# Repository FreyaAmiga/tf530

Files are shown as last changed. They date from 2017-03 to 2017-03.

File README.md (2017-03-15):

# TF530

** WARNING THIS IS BETA AT THE MOMENT

This repository contains all the files needed to produce a copy of my accelerator board.

The CPLD Required is a XC9572XL-10VQ64

Everything in this repository is released under the GNU GPLv2. You may create or base commercial PCBs from the work in this repository but you must make the sources for all derivative work available. 

## Firmware / Requirements

  * Xilinx ISE, 14.7 (the final version - other versions may work but this is the one I support)
  * JTAG Adaptor

[For more information visit my channel](https://www.youtube.com/c/TerribleFire)

##License

This project and all the files contained are released under the GNU GPLv2. If you build a modified version of the board you must supply the end user with all the sources (this can be a web link).

##The TerribleFire 530 board (Revision 2)

This board is now in Beta. It may not work in all circumstances but it has been verified to boot AmigaOS 1.3, 2.05 and 3.1 and run various games and desktop apps at 25Mhz. Operation is not guarunteed to be crash free but will work in most "happy path" situations.

I have only verified the HD interface with Compact Flash cards.
I have verified this board boots on Amiga 500 Rev 5, 6a, 8.1a

To buy 10 blank copies of the revision 2 board follow the following link.

http://dirtypcbs.com/store/designer/details/12476/1330/tf530-rev2b-zip

(Terrible Fire gets a $2 "cut" for each order... in reality this is a downpayment on future prototype board orders).

I accept no responsibiltiy for any damage to any equipment that results from the use of this board. IT IS ENTIRELY AT YOUR OWN RISK!

## Installation

Installation is exactly the same as the Kipper2k A508. Refer to http://www.kipper2k.com/a500fastmem.html

You need to connect the OVR and INT2 signals to the A500 header port. 

## What does the board look like

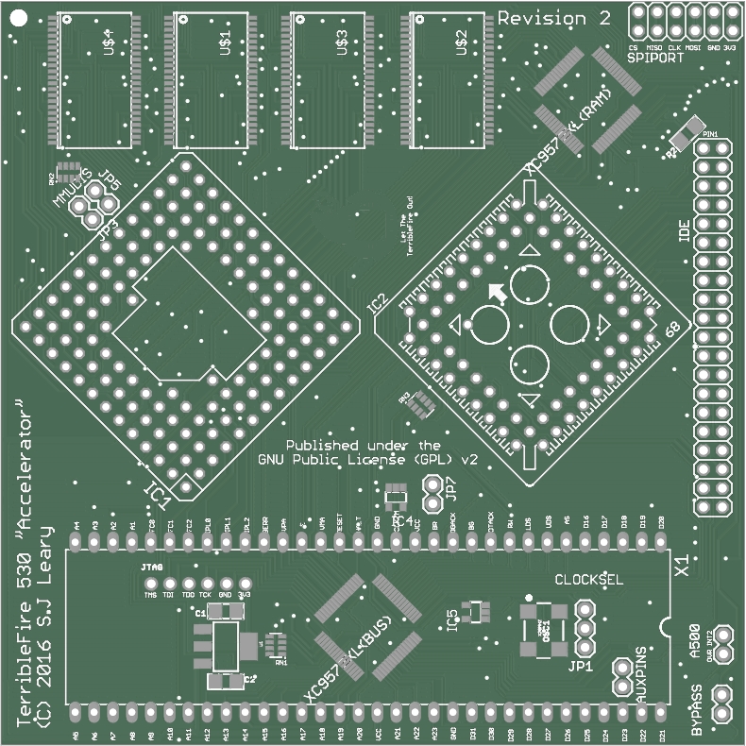
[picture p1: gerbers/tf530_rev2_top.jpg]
Image of Top of PCB


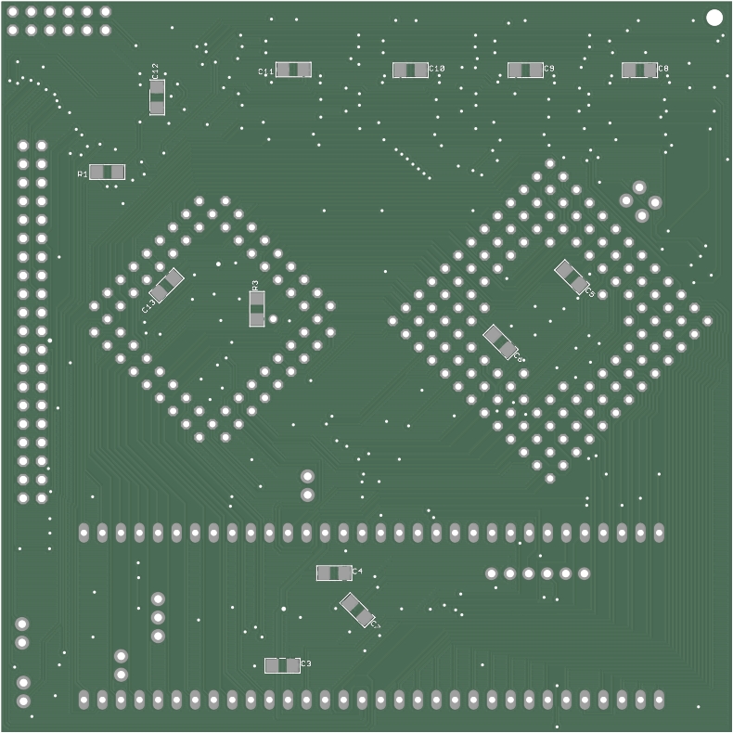
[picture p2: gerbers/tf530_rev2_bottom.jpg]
Image of Bottom of PCB


## The BOM 

| Qty | Value | Device | Package | Parts | Description | 
|-----|---|---|---|---|---|
| 1 | | MC68030RC | MPGA128 | IC1 | 68xxx PROCESSOR | 
| 1 | | MC68881FN-SOC | PLCC68-S | IC2 | 68xxx PROCESSOR |
| 1 | 10K | RESISTOR1206 | 1206 | R3 | Resistors |
| 13  | 10uF | CAP_CERAMIC1206 | 1206 | C1, C2, C3, C4, C5, C6, C7, C8, C9, C10, C11, C12, C13 | Ceramic Capacitors | 
| 2 | 47K | RESISTOR1206 | 1206 | R1, R2 | Resistors | 
| 2 | 74LVC1G17DBV | 74LVC1G17DBV | SOT23-5 | IC4, IC5 | Single Schmitt-Trigger Buffer | 
| 1 | A500 | JUMPER-2PTH | 1X02 | A500 | Jumper | 
| 4 | AS7C4096A-12TIN | AS7C4096A-12TCN | TSOP44-II | U$1, U$2, U$3, U$4 | |  
| 1 | AUXPINS | JUMPER-2PTH | 1X02 | AUXPINS | Jumper | 
| 1 | BYPASS | JUMPER-2PTH | 1X02 | BYPASS | Jumper (optional) | 
| 3 | CAY16-103J4LF | CAY16-103J4LF | RESCAXE80P320X160-8N | RN1, RN2, RN3 | Res Thick Film Array 10K Ohm  | 
| 1 | CDIS | JUMPER-2PTH | 1X02 | JP5 | Jumper |
| 1 | CLOCKSEL | JUMPER-3PTH | 1X03 | JP1 | | 
| 1 | EXT5V | JUMPER-2PTH | 1X02 | JP7 | Jumper |
| 1 | IDE CONNECTOR | PINHD-2X20 | 2X20 | IDE | PIN HEADER |
| 1 | JTAG | HEADER-1X6ROUND | 1X06_ROUND | JTAG | PIN HEADER |
| 1 | LM1117 | V_REG_LM1117SOT223 | SOT223 | U1 | 3.3V Voltage  Regulator LM1117 |
| 1 | MC68000 | MC68000P | DIL64 | X1 | 68xxx PROCESSOR SOCKET | 
| 1 | MMUDIS | JUMPER-2PTH | 1X02 | JP3 | Jumper | 
| 1 | SPI PORT | PINHD-2X6 | 2X06 | SPIPORT | PIN HEADER | 
| 1 | X24MHZ | OSCILLATOR | OSC_7X5MM | OSC1 | 24 Mhz llators |
| 2 | XC9572XL-10VQ64 | XC9572XL-VQ64 | VQ64 | XC9572XL(BUS), XC9572XL(RAM) | |

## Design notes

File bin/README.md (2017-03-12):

TF530 Binary Files
==================

These are binary files that i create to make life easy for people bringing up the TF530.

File Description

The .xsvf is a single file containing both JED files that should be playable by an xsvf player. If you dont have one you will need the jed files.

<date>_tf530_bus.jed - File for the first CPLD in the chain.
<date>_tf530_ram.jed - File for the second CPLD in the chain.

~~~~
  Chain Diagram
  
            -------         -------        
  TDI ---- |       |-->----|       | - - -|
           |  BUS  |       |  RAM  |      |
           |       |       |       |      |
            -------         -------       |
                                          |
  TDO -----<-------------------------<-----
~~~~

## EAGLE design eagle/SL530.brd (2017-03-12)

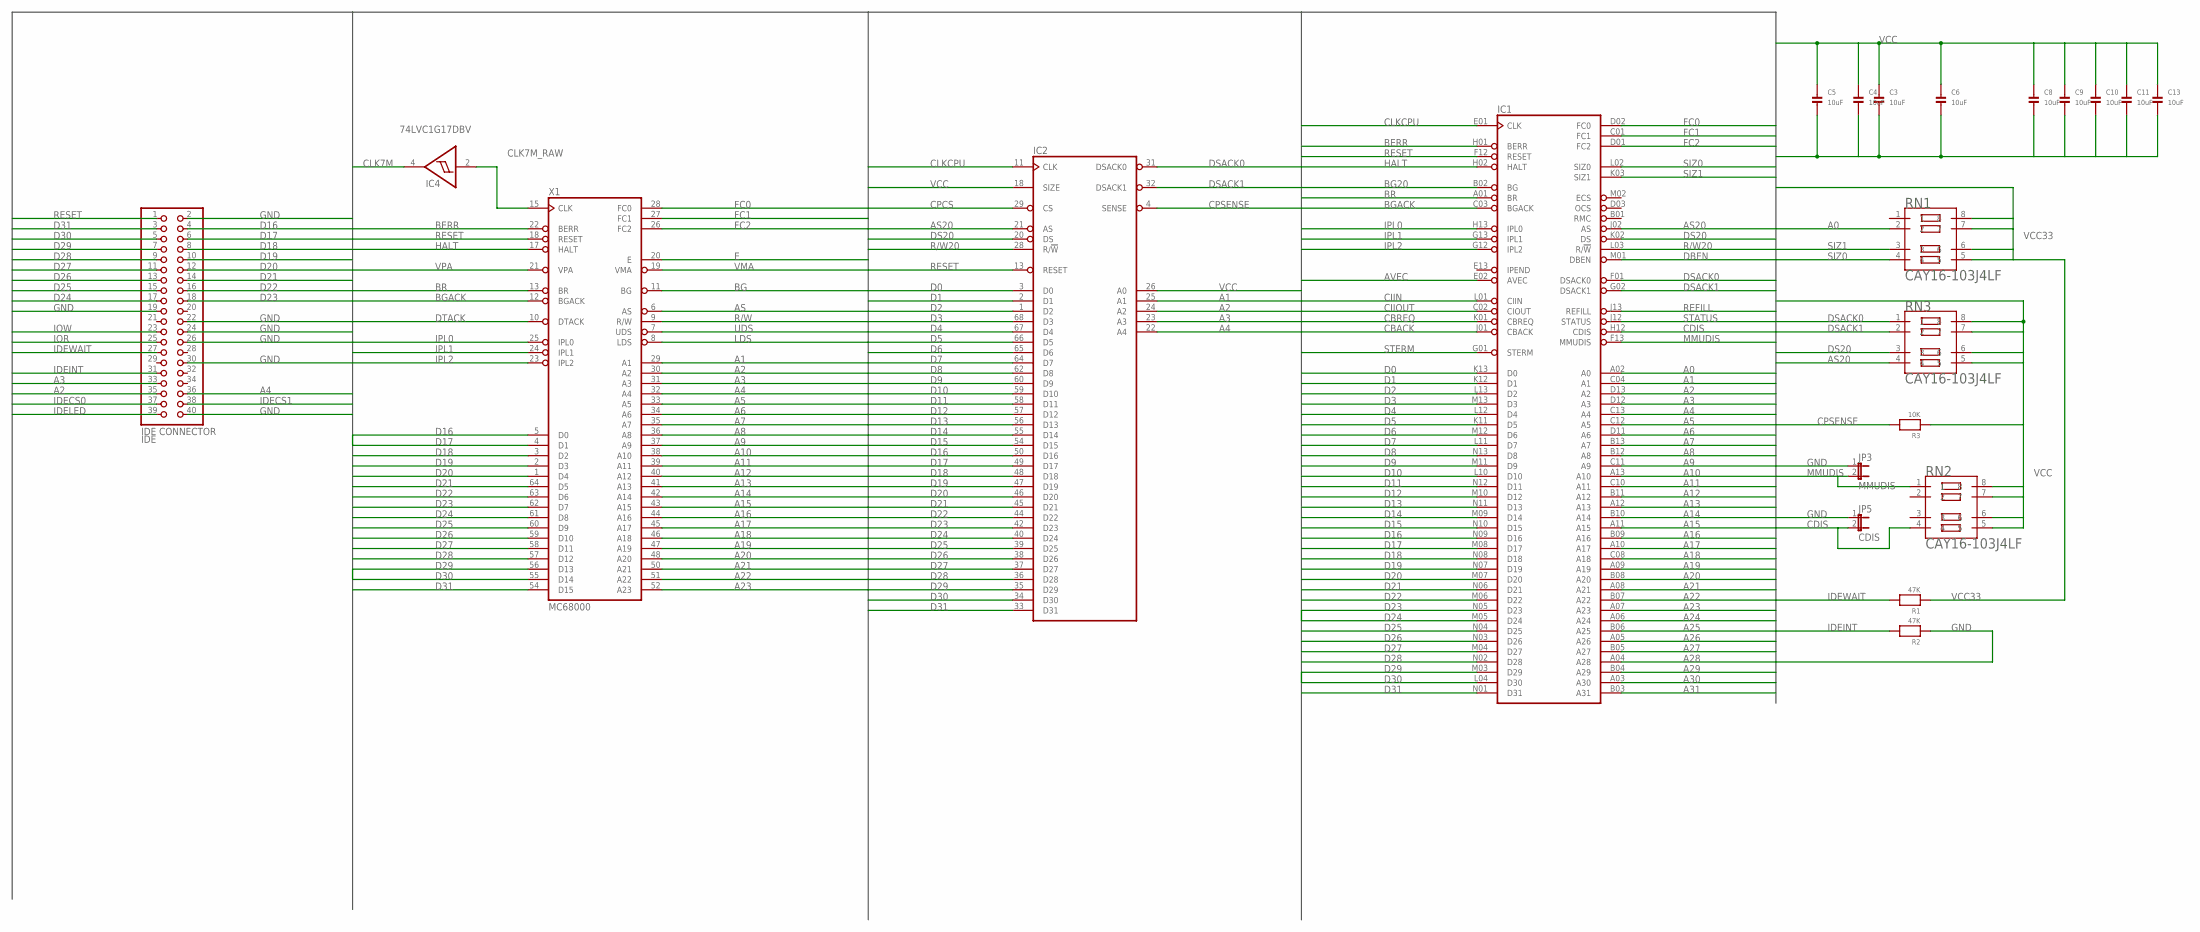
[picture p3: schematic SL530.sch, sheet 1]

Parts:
C3, C4, C5, C6, C8, C9, C10, C11, C13: 10uF; 1206
IC1: MC68030RC; MPGA128
IC2: MC68881FN-SOC; PLCC68-S
IC4: 74LVC1G17DBV; SOT23-5
IDE: IDE CONNECTOR; 2X20
JP3: MMUDIS; 1X02
JP5: CDIS; 1X02
R1, R2: 47K; 1206
R3: 10K; 1206
RN1, RN2, RN3: CAY16-103J4LF; RESCAXE80P320X160-8N
X1: MC68000; DIL64

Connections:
A0: IC1.A02 (A0), RN1.2; also elsewhere on the board
A1: IC1.C04 (A1), IC2.25 (A1), X1.29 (A1); also elsewhere on the board
A2: IC1.D13 (A2), IC2.24 (A2), IDE.35, X1.30 (A2); also elsewhere on the board
A3: IC1.D12 (A3), IC2.23 (A3), IDE.33, X1.31 (A3); also elsewhere on the board
A4: IC1.C13 (A4), IC2.22 (A4), IDE.36, X1.32 (A4); also elsewhere on the board
A5: IC1.C12 (A5), X1.33 (A5); also elsewhere on the board
A6: IC1.D11 (A6), X1.34 (A6); also elsewhere on the board
A7: IC1.B13 (A7), X1.35 (A7); also elsewhere on the board
A8: IC1.B12 (A8), X1.36 (A8); also elsewhere on the board
A9: IC1.C11 (A9), X1.37 (A9); also elsewhere on the board
A10: IC1.A13 (A10), X1.38 (A10); also elsewhere on the board
A11: IC1.C10 (A11), X1.39 (A11); also elsewhere on the board
A12: IC1.B11 (A12), X1.40 (A12); also elsewhere on the board
A13: IC1.A12 (A13), X1.41 (A13); also elsewhere on the board
A14: IC1.B10 (A14), X1.42 (A14); also elsewhere on the board
A15: IC1.A11 (A15), X1.43 (A15); also elsewhere on the board
A16: IC1.B09 (A16), X1.44 (A16); also elsewhere on the board
A17: IC1.A10 (A17), X1.45 (A17); also elsewhere on the board
A18: IC1.C08 (A18), X1.46 (A18); also elsewhere on the board
A19: IC1.A09 (A19), X1.47 (A19); also elsewhere on the board
A20: IC1.B08 (A20), X1.48 (A20); also elsewhere on the board
A21: IC1.A08 (A21), X1.50 (A21); also elsewhere on the board
A22: IC1.B07 (A22), X1.51 (A22); also elsewhere on the board
A23: IC1.A07 (A23), X1.52 (A23); also elsewhere on the board
A24: IC1.A06 (A24)
A25: IC1.B06 (A25)
A26: IC1.A05 (A26)
A27: IC1.B05 (A27)
A28: IC1.A04 (A28)
A29: IC1.B04 (A29)
A30: IC1.A03 (A30)
A31: IC1.B03 (A31)
AS: X1.6 (AS); also elsewhere on the board
AS20: IC1.J02 (AS), IC2.21 (AS), RN3.4; also elsewhere on the board
AVEC: IC1.E02 (AVEC); also elsewhere on the board
BERR: IC1.H01 (BERR), X1.22 (BERR); also elsewhere on the board
BG: X1.11 (BG); also elsewhere on the board
BG20: IC1.B02 (BG); also elsewhere on the board
BGACK: IC1.C03 (BGACK), X1.12 (BGACK); also elsewhere on the board
BR: IC1.A01 (BR), X1.13 (BR)
CBACK: IC1.J01 (CBACK); also elsewhere on the board
CBREQ: IC1.K01 (CBREQ); also elsewhere on the board
CDIS: IC1.H12 (CDIS), JP5.2, RN2.4
CIIN: IC1.L01 (CIIN); also elsewhere on the board
CIIOUT: IC1.C02 (CIOUT)
CLK7M: IC4.4 (O); also elsewhere on the board
CLK7M_RAW: IC4.2 (I), X1.15 (CLK)
CLKCPU: IC1.E01 (CLK), IC2.11 (CLK); also elsewhere on the board
CPCS: IC2.29 (CS); also elsewhere on the board
CPSENSE: IC2.4 (SENSE), R3.2; also elsewhere on the board
D0: IC1.K13 (D0), IC2.3 (D0); also elsewhere on the board
D1: IC1.K12 (D1), IC2.2 (D1); also elsewhere on the board
D2: IC1.L13 (D2), IC2.1 (D2); also elsewhere on the board
D3: IC1.M13 (D3), IC2.68 (D3); also elsewhere on the board
D4: IC1.L12 (D4), IC2.67 (D4); also elsewhere on the board
D5: IC1.K11 (D5), IC2.66 (D5); also elsewhere on the board
D6: IC1.M12 (D6), IC2.65 (D6); also elsewhere on the board
D7: IC1.L11 (D7), IC2.64 (D7); also elsewhere on the board
D8: IC1.N13 (D8), IC2.62 (D8); also elsewhere on the board
D9: IC1.M11 (D9), IC2.60 (D9); also elsewhere on the board
D10: IC1.L10 (D10), IC2.59 (D10); also elsewhere on the board
D11: IC1.N12 (D11), IC2.58 (D11); also elsewhere on the board
D12: IC1.M10 (D12), IC2.57 (D12); also elsewhere on the board
D13: IC1.N11 (D13), IC2.56 (D13); also elsewhere on the board
D14: IC1.M09 (D14), IC2.55 (D14); also elsewhere on the board
D15: IC1.N10 (D15), IC2.54 (D15); also elsewhere on the board
D16: IC1.N09 (D16), IC2.50 (D16), IDE.4, X1.5 (D0); also elsewhere on the board
D17: IC1.M08 (D17), IC2.49 (D17), IDE.6, X1.4 (D1); also elsewhere on the board
D18: IC1.N08 (D18), IC2.48 (D18), IDE.8, X1.3 (D2); also elsewhere on the board
D19: IC1.N07 (D19), IC2.47 (D19), IDE.10, X1.2 (D3); also elsewhere on the board
D20: IC1.M07 (D20), IC2.46 (D20), IDE.12, X1.1 (D4); also elsewhere on the board
D21: IC1.N06 (D21), IC2.45 (D21), IDE.14, X1.64 (D5); also elsewhere on the board
D22: IC1.M06 (D22), IC2.44 (D22), IDE.16, X1.63 (D6); also elsewhere on the board
D23: IC1.N05 (D23), IC2.42 (D23), IDE.18, X1.62 (D7); also elsewhere on the board
D24: IC1.M05 (D24), IC2.40 (D24), IDE.17, X1.61 (D8); also elsewhere on the board
D25: IC1.N04 (D25), IC2.39 (D25), IDE.15, X1.60 (D9); also elsewhere on the board
D26: IC1.N03 (D26), IC2.38 (D26), IDE.13, X1.59 (D10); also elsewhere on the board
D27: IC1.M04 (D27), IC2.37 (D27), IDE.11, X1.58 (D11); also elsewhere on the board
D28: IC1.N02 (D28), IC2.36 (D28), IDE.9, X1.57 (D12); also elsewhere on the board
D29: IC1.M03 (D29), IC2.35 (D29), IDE.7, X1.56 (D13); also elsewhere on the board
D30: IC1.L04 (D30), IC2.34 (D30), IDE.5, X1.55 (D14); also elsewhere on the board
D31: IC1.N01 (D31), IC2.33 (D31), IDE.3, X1.54 (D15); also elsewhere on the board
DBEN: IC1.M01 (DBEN)
DS20: IC1.K02 (DS), IC2.20 (DS), RN3.3; also elsewhere on the board
DSACK0: IC1.F01 (DSACK0), IC2.31 (DSACK0), RN3.1; also elsewhere on the board
DSACK1: IC1.G02 (DSACK1), IC2.32 (DSACK1), RN3.2; also elsewhere on the board
DTACK: X1.10 (DTACK); also elsewhere on the board
E: X1.20 (E); also elsewhere on the board
FC0: IC1.D02 (FC0), X1.28 (FC0); also elsewhere on the board
FC1: IC1.C01 (FC1), X1.27 (FC1); also elsewhere on the board
FC2: IC1.D01 (FC2), X1.26 (FC2); also elsewhere on the board
GND: C3.2, C4.2, C5.2, C6.2, C8.2, C9.2, C10.2, C11.2, C13.2, IC1.C05 (GND), IC1.C07 (GND), IC1.C09 (GND), IC1.E03 (GND), IC1.E11 (GND), IC1.F03 (GND), IC1.G03 (GND), IC1.G11 (GND), IC1.J03 (GND), IC1.J11 (GND), IC1.L05 (GND), IC1.L07 (GND), IC1.L08 (GND), IC1.L09 (GND), IC2.5 (GND), IC2.6 (GND), IC2.7 (GND), IC2.8 (GND), IC2.9 (GND), IC2.12 (GND), IC2.14 (GND), IC2.19 (GND), IC2.30 (GND), IC2.41 (GND), IC2.51 (GND), IC2.63 (GND), IC4.3 (GND), IDE.2, IDE.19, IDE.22, IDE.24, IDE.26, IDE.30, IDE.40, JP3.1, JP5.1, R2.1, X1.16 (GND), X1.53 (GND); also elsewhere on the board
HALT: IC1.H02 (HALT), X1.17 (HALT); also elsewhere on the board
IDECS0: IDE.37; also elsewhere on the board
IDECS1: IDE.38; also elsewhere on the board
IDEINT: IDE.31, R2.2; also elsewhere on the board
IDELED: IDE.39
IDEWAIT: IDE.27, R1.2; also elsewhere on the board
IOR: IDE.25; also elsewhere on the board
IOW: IDE.23; also elsewhere on the board
IPL0: IC1.H13 (IPL0), X1.25 (IPL0)
IPL1: IC1.G13 (IPL1), X1.24 (IPL1)
IPL2: IC1.G12 (IPL2), X1.23 (IPL2)
LDS: X1.8 (LDS); also elsewhere on the board
MMUDIS: IC1.F13 (MMUDIS), JP3.2, RN2.1
R/W: X1.9 (R/W); also elsewhere on the board
R/W20: IC1.L03 (R/!W), IC2.28 (R/!W); also elsewhere on the board
REFILL: IC1.J13 (REFILL)
RESET: IC1.F12 (RESET), IC2.13 (RESET), IDE.1, X1.18 (RESET); also elsewhere on the board
SIZ0: IC1.L02 (SIZ0), RN1.4; also elsewhere on the board
SIZ1: IC1.K03 (SIZ1), RN1.3; also elsewhere on the board
STATUS: IC1.J12 (STATUS)
STERM: IC1.G01 (STERM); also elsewhere on the board
UDS: X1.7 (UDS); also elsewhere on the board
VCC: C3.1, C4.1, C5.1, C6.1, C8.1, C9.1, C10.1, C11.1, C13.1, IC1.C06 (VCC), IC1.D04 (VCC), IC1.D10 (VCC), IC1.F02 (VCC), IC1.F11 (VCC), IC1.H03 (VCC), IC1.H11 (VCC), IC1.K04 (VCC), IC1.K10 (VCC), IC1.L06 (VCC), IC2.10 (VCC), IC2.16 (VCC), IC2.17 (VCC), IC2.18 (SIZE), IC2.26 (A0), IC2.27 (VCC), IC2.43 (VCC), IC2.52 (VCC), IC2.53 (VCC), IC2.61 (VCC), IC4.5 (VCC), R3.1, RN2.5, RN2.6, RN2.7, RN2.8, RN3.5, RN3.6, RN3.7, RN3.8, X1.14 (VCC), X1.49 (VCC); also elsewhere on the board
VCC33: R1.1, RN1.5, RN1.6, RN1.7, RN1.8; also elsewhere on the board
VMA: X1.19 (VMA); also elsewhere on the board
VPA: X1.21 (VPA); also elsewhere on the board

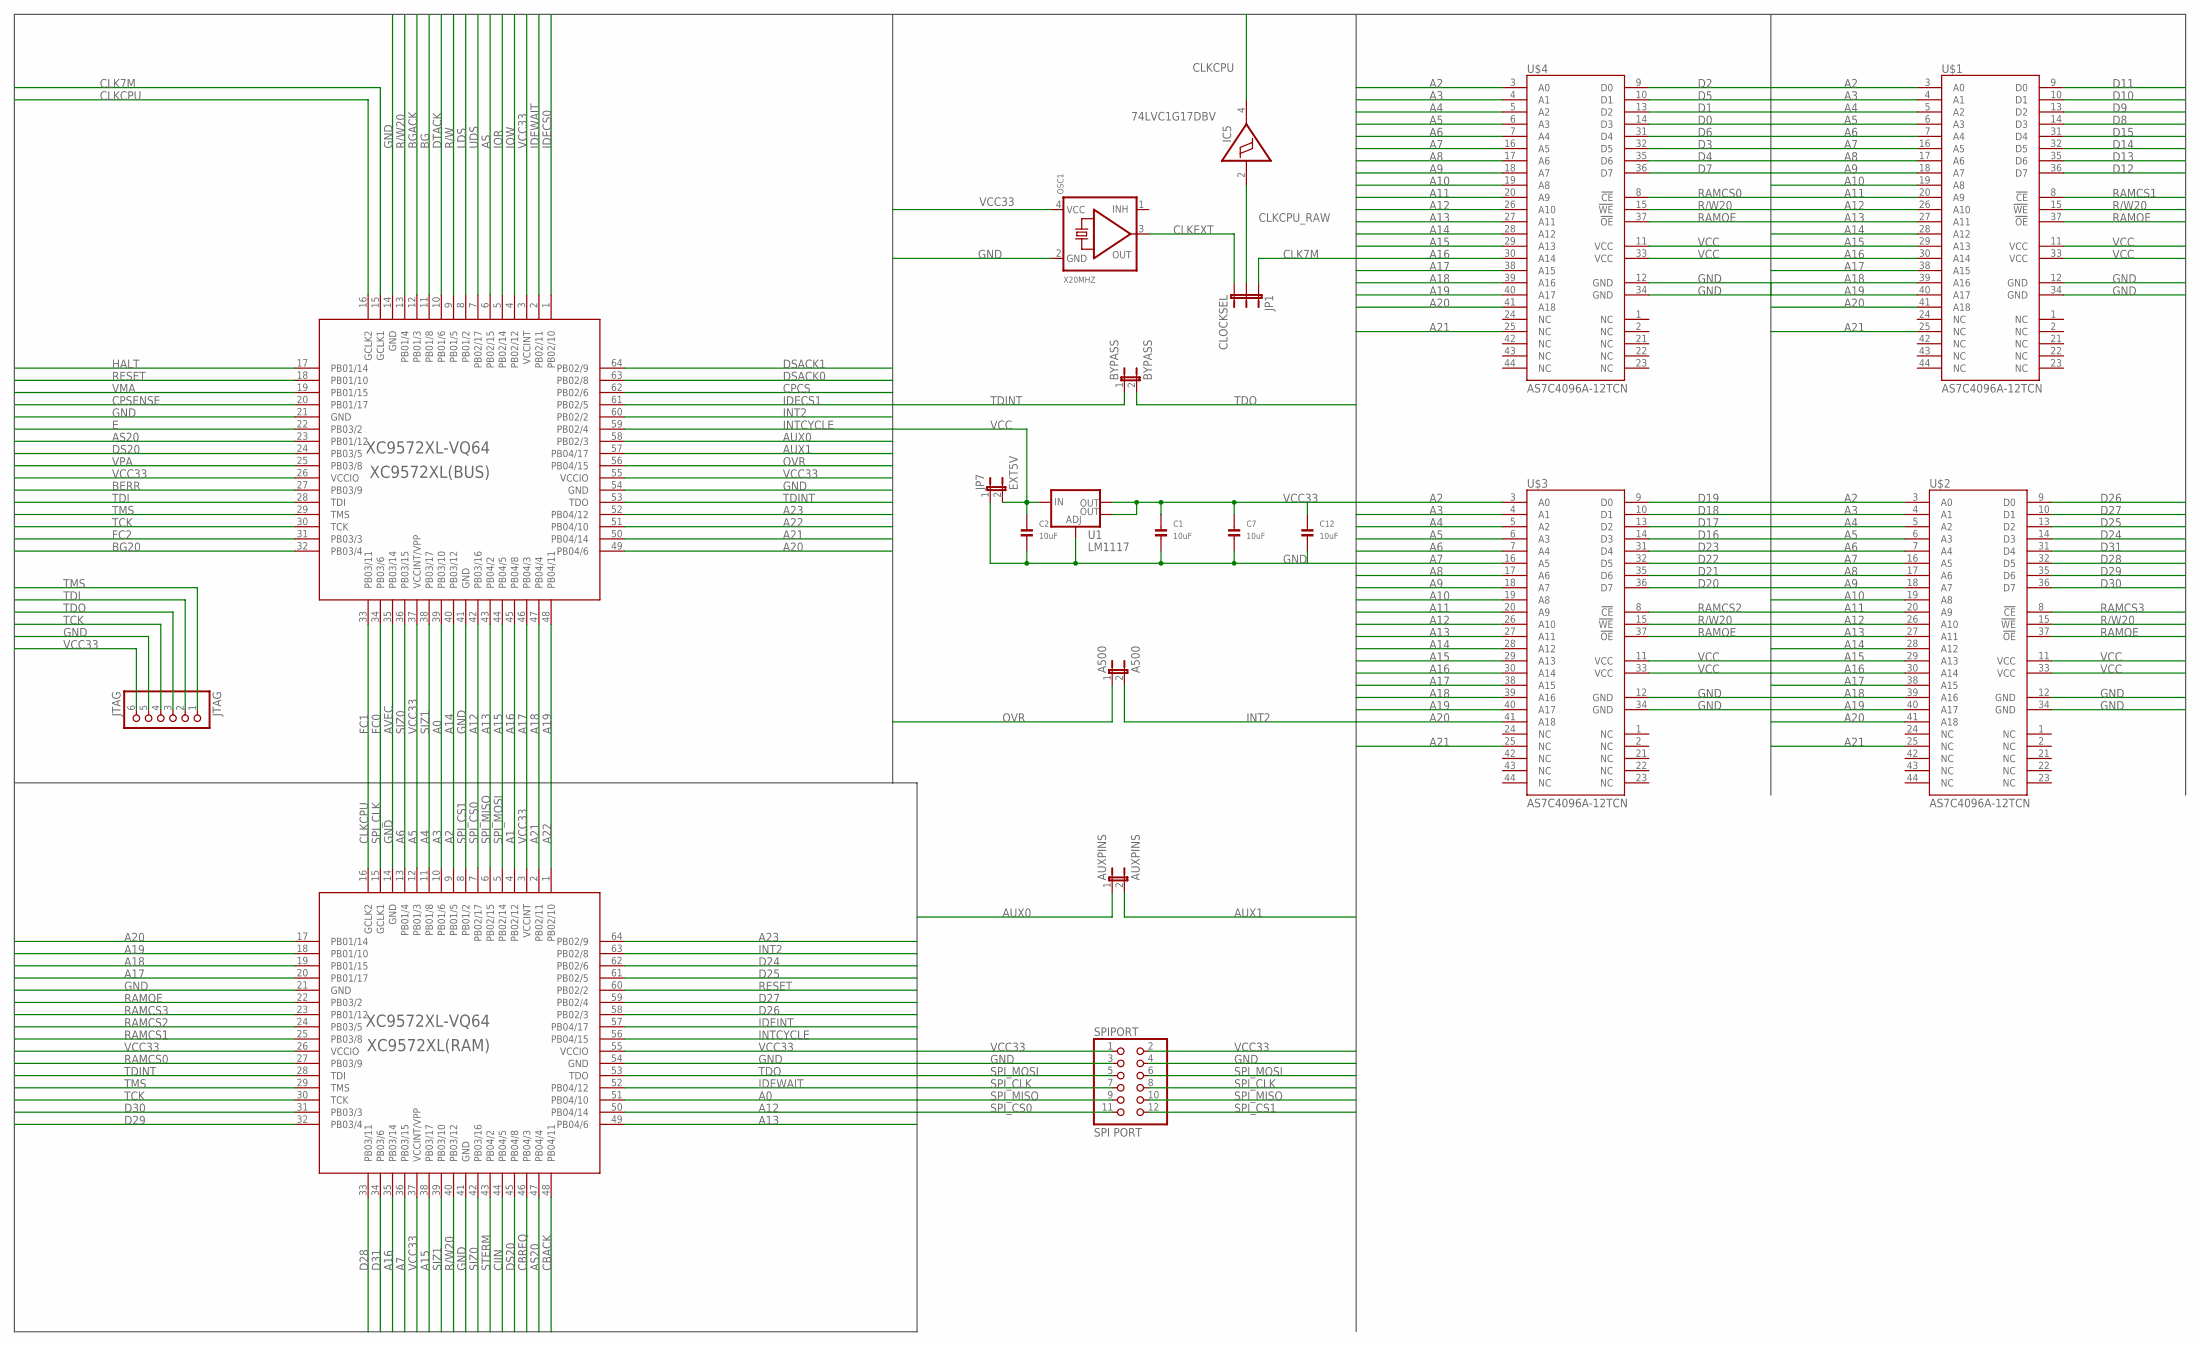
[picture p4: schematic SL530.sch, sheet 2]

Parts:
A500: A500; 1X02
AUXPINS: AUXPINS; 1X02
BYPASS: BYPASS; 1X02
C1, C2, C7, C12: 10uF; 1206
IC5: 74LVC1G17DBV; SOT23-5
JP1: CLOCKSEL; 1X03
JP7: EXT5V; 1X02
JTAG: JTAG; 1X06_ROUND
OSC1: X20MHZ; OSC_7X5MM
SPIPORT: SPI PORT; 2X06
U1: LM1117; SOT223
U$1, U$2, U$3, U$4: AS7C4096A-12TCN; TSOP44-II
XC9572XL(BUS), XC9572XL(RAM): XC9572XL-VQ64; VQ64

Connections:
A0: XC9572XL(BUS).39 (PB03/10), XC9572XL(RAM).51 (PB04/10); also elsewhere on the board
A1: XC9572XL(RAM).4 (PB02/12); also elsewhere on the board
A2: U$1.3 (A0), U$2.3 (A0), U$3.3 (A0), U$4.3 (A0), XC9572XL(RAM).9 (PB01/5); also elsewhere on the board
A3: U$1.4 (A1), U$2.4 (A1), U$3.4 (A1), U$4.4 (A1), XC9572XL(RAM).10 (PB01/6); also elsewhere on the board
A4: U$1.5 (A2), U$2.5 (A2), U$3.5 (A2), U$4.5 (A2), XC9572XL(RAM).11 (PB01/8); also elsewhere on the board
A5: U$1.6 (A3), U$2.6 (A3), U$3.6 (A3), U$4.6 (A3), XC9572XL(RAM).12 (PB01/3); also elsewhere on the board
A6: U$1.7 (A4), U$2.7 (A4), U$3.7 (A4), U$4.7 (A4), XC9572XL(RAM).13 (PB01/4); also elsewhere on the board
A7: U$1.16 (A5), U$2.16 (A5), U$3.16 (A5), U$4.16 (A5), XC9572XL(RAM).36 (PB03/15); also elsewhere on the board
A8: U$1.17 (A6), U$2.17 (A6), U$3.17 (A6), U$4.17 (A6); also elsewhere on the board
A9: U$1.18 (A7), U$2.18 (A7), U$3.18 (A7), U$4.18 (A7); also elsewhere on the board
A10: U$1.19 (A8), U$2.19 (A8), U$3.19 (A8), U$4.19 (A8); also elsewhere on the board
A11: U$1.20 (A9), U$2.20 (A9), U$3.20 (A9), U$4.20 (A9); also elsewhere on the board
A12: U$1.26 (A10), U$2.26 (A10), U$3.26 (A10), U$4.26 (A10), XC9572XL(BUS).42 (PB03/16), XC9572XL(RAM).50 (PB04/14); also elsewhere on the board
A13: U$1.27 (A11), U$2.27 (A11), U$3.27 (A11), U$4.27 (A11), XC9572XL(BUS).43 (PB04/2), XC9572XL(RAM).49 (PB04/6); also elsewhere on the board
A14: U$1.28 (A12), U$2.28 (A12), U$3.28 (A12), U$4.28 (A12), XC9572XL(BUS).40 (PB03/12); also elsewhere on the board
A15: U$1.29 (A13), U$2.29 (A13), U$3.29 (A13), U$4.29 (A13), XC9572XL(BUS).44 (PB04/5), XC9572XL(RAM).38 (PB03/17); also elsewhere on the board
A16: U$1.30 (A14), U$2.30 (A14), U$3.30 (A14), U$4.30 (A14), XC9572XL(BUS).45 (PB04/8), XC9572XL(RAM).35 (PB03/14); also elsewhere on the board
A17: U$1.38 (A15), U$2.38 (A15), U$3.38 (A15), U$4.38 (A15), XC9572XL(BUS).46 (PB04/3), XC9572XL(RAM).20 (PB01/17); also elsewhere on the board
A18: U$1.39 (A16), U$2.39 (A16), U$3.39 (A16), U$4.39 (A16), XC9572XL(BUS).47 (PB04/4), XC9572XL(RAM).19 (PB01/15); also elsewhere on the board
A19: U$1.40 (A17), U$2.40 (A17), U$3.40 (A17), U$4.40 (A17), XC9572XL(BUS).48 (PB04/11), XC9572XL(RAM).18 (PB01/10); also elsewhere on the board
A20: U$1.41 (A18), U$2.41 (A18), U$3.41 (A18), U$4.41 (A18), XC9572XL(BUS).49 (PB04/6), XC9572XL(RAM).17 (PB01/14); also elsewhere on the board
A21: U$1.25 (NC), U$2.25 (NC), U$3.25 (NC), U$4.25 (NC), XC9572XL(BUS).50 (PB04/14), XC9572XL(RAM).2 (PB02/11); also elsewhere on the board
A22: XC9572XL(BUS).51 (PB04/10), XC9572XL(RAM).1 (PB02/10); also elsewhere on the board
A23: XC9572XL(BUS).52 (PB04/12), XC9572XL(RAM).64 (PB02/9); also elsewhere on the board
AS: XC9572XL(BUS).6 (PB02/15); also elsewhere on the board
AS20: XC9572XL(BUS).23 (PB01/12), XC9572XL(RAM).47 (PB04/4); also elsewhere on the board
AUX0: AUXPINS.1, XC9572XL(BUS).58 (PB02/3)
AUX1: AUXPINS.2, XC9572XL(BUS).57 (PB04/17)
AVEC: XC9572XL(BUS).35 (PB03/14); also elsewhere on the board
BERR: XC9572XL(BUS).27 (PB03/9); also elsewhere on the board
BG: XC9572XL(BUS).11 (PB01/8); also elsewhere on the board
BG20: XC9572XL(BUS).32 (PB03/4); also elsewhere on the board
BGACK: XC9572XL(BUS).12 (PB01/3); also elsewhere on the board
CBACK: XC9572XL(RAM).48 (PB04/11); also elsewhere on the board
CBREQ: XC9572XL(RAM).46 (PB04/3); also elsewhere on the board
CIIN: XC9572XL(RAM).44 (PB04/5); also elsewhere on the board
CLK7M: JP1.1, XC9572XL(BUS).15 (GCLK1); also elsewhere on the board
CLKCPU: IC5.4 (O), XC9572XL(BUS).16 (GCLK2), XC9572XL(RAM).16 (GCLK2); also elsewhere on the board
CLKCPU_RAW: IC5.2 (I), JP1.2
CLKEXT: JP1.3, OSC1.3 (OUT)
CPCS: XC9572XL(BUS).62 (PB02/6); also elsewhere on the board
CPSENSE: XC9572XL(BUS).20 (PB01/17); also elsewhere on the board
D0: U$4.14 (D3); also elsewhere on the board
D1: U$4.13 (D2); also elsewhere on the board
D2: U$4.9 (D0); also elsewhere on the board
D3: U$4.32 (D5); also elsewhere on the board
D4: U$4.35 (D6); also elsewhere on the board
D5: U$4.10 (D1); also elsewhere on the board
D6: U$4.31 (D4); also elsewhere on the board
D7: U$4.36 (D7); also elsewhere on the board
D8: U$1.14 (D3); also elsewhere on the board
D9: U$1.13 (D2); also elsewhere on the board
D10: U$1.10 (D1); also elsewhere on the board
D11: U$1.9 (D0); also elsewhere on the board
D12: U$1.36 (D7); also elsewhere on the board
D13: U$1.35 (D6); also elsewhere on the board
D14: U$1.32 (D5); also elsewhere on the board
D15: U$1.31 (D4); also elsewhere on the board
D16: U$3.14 (D3); also elsewhere on the board
D17: U$3.13 (D2); also elsewhere on the board
D18: U$3.10 (D1); also elsewhere on the board
D19: U$3.9 (D0); also elsewhere on the board
D20: U$3.36 (D7); also elsewhere on the board
D21: U$3.35 (D6); also elsewhere on the board
D22: U$3.32 (D5); also elsewhere on the board
D23: U$3.31 (D4); also elsewhere on the board
D24: U$2.14 (D3), XC9572XL(RAM).62 (PB02/6); also elsewhere on the board
D25: U$2.13 (D2), XC9572XL(RAM).61 (PB02/5); also elsewhere on the board
D26: U$2.9 (D0), XC9572XL(RAM).58 (PB02/3); also elsewhere on the board
D27: U$2.10 (D1), XC9572XL(RAM).59 (PB02/4); also elsewhere on the board
D28: U$2.32 (D5), XC9572XL(RAM).33 (PB03/11); also elsewhere on the board
D29: U$2.35 (D6), XC9572XL(RAM).32 (PB03/4); also elsewhere on the board
D30: U$2.36 (D7), XC9572XL(RAM).31 (PB03/3); also elsewhere on the board
D31: U$2.31 (D4), XC9572XL(RAM).34 (PB03/6); also elsewhere on the board
DS20: XC9572XL(BUS).24 (PB03/5), XC9572XL(RAM).45 (PB04/8); also elsewhere on the board
DSACK0: XC9572XL(BUS).63 (PB02/8); also elsewhere on the board
DSACK1: XC9572XL(BUS).64 (PB02/9); also elsewhere on the board
DTACK: XC9572XL(BUS).10 (PB01/6); also elsewhere on the board
E: XC9572XL(BUS).22 (PB03/2); also elsewhere on the board
FC0: XC9572XL(BUS).34 (PB03/6); also elsewhere on the board
FC1: XC9572XL(BUS).33 (PB03/11); also elsewhere on the board
FC2: XC9572XL(BUS).31 (PB03/3); also elsewhere on the board
GND: C1.2, C2.2, C7.2, C12.2, IC5.3 (GND), JP7.1, JTAG.5, OSC1.2 (GND), SPIPORT.3, SPIPORT.4, U1.1 (ADJ), U$1.12 (GND), U$1.34 (GND), U$2.12 (GND), U$2.34 (GND), U$3.12 (GND), U$3.34 (GND), U$4.12 (GND), U$4.34 (GND), XC9572XL(BUS).14 (GND), XC9572XL(BUS).21 (GND), XC9572XL(BUS).41 (GND), XC9572XL(BUS).54 (GND), XC9572XL(RAM).14 (GND), XC9572XL(RAM).21 (GND), XC9572XL(RAM).41 (GND), XC9572XL(RAM).54 (GND); also elsewhere on the board
HALT: XC9572XL(BUS).17 (PB01/14); also elsewhere on the board
IDECS0: XC9572XL(BUS).1 (PB02/10); also elsewhere on the board
IDECS1: XC9572XL(BUS).61 (PB02/5); also elsewhere on the board
IDEINT: XC9572XL(RAM).57 (PB04/17); also elsewhere on the board
IDEWAIT: XC9572XL(BUS).2 (PB02/11), XC9572XL(RAM).52 (PB04/12); also elsewhere on the board
INT2: A500.2, XC9572XL(BUS).60 (PB02/2), XC9572XL(RAM).63 (PB02/8)
INTCYCLE: XC9572XL(BUS).59 (PB02/4), XC9572XL(RAM).56 (PB04/15)
IOR: XC9572XL(BUS).5 (PB02/14); also elsewhere on the board
IOW: XC9572XL(BUS).4 (PB02/12); also elsewhere on the board
LDS: XC9572XL(BUS).8 (PB01/2); also elsewhere on the board
OVR: A500.1, XC9572XL(BUS).56 (PB04/15)
R/W: XC9572XL(BUS).9 (PB01/5); also elsewhere on the board
R/W20: U$1.15 (!WE), U$2.15 (!WE), U$3.15 (!WE), U$4.15 (!WE), XC9572XL(BUS).13 (PB01/4), XC9572XL(RAM).40 (PB03/12); also elsewhere on the board
RAMCS0: U$4.8 (!CE), XC9572XL(RAM).27 (PB03/9)
RAMCS1: U$1.8 (!CE), XC9572XL(RAM).25 (PB03/8)
RAMCS2: U$3.8 (!CE), XC9572XL(RAM).24 (PB03/5)
RAMCS3: U$2.8 (!CE), XC9572XL(RAM).23 (PB01/12)
RAMOE: U$1.37 (!OE), U$2.37 (!OE), U$3.37 (!OE), U$4.37 (!OE), XC9572XL(RAM).22 (PB03/2)
RESET: XC9572XL(BUS).18 (PB01/10), XC9572XL(RAM).60 (PB02/2); also elsewhere on the board
SIZ0: XC9572XL(BUS).36 (PB03/15), XC9572XL(RAM).42 (PB03/16); also elsewhere on the board
SIZ1: XC9572XL(BUS).38 (PB03/17), XC9572XL(RAM).39 (PB03/10); also elsewhere on the board
SPI_CLK: SPIPORT.7, SPIPORT.8, XC9572XL(RAM).15 (GCLK1)
SPI_CS0: SPIPORT.11, XC9572XL(RAM).7 (PB02/17)
SPI_CS1: SPIPORT.12, XC9572XL(RAM).8 (PB01/2)
SPI_MISO: SPIPORT.9, SPIPORT.10, XC9572XL(RAM).6 (PB02/15)
SPI_MOSI: SPIPORT.5, SPIPORT.6, XC9572XL(RAM).5 (PB02/14)
STERM: XC9572XL(RAM).43 (PB04/2); also elsewhere on the board
TCK: JTAG.4, XC9572XL(BUS).30 (TCK), XC9572XL(RAM).30 (TCK)
TDI: JTAG.2, XC9572XL(BUS).28 (TDI)
TDINT: BYPASS.1, XC9572XL(BUS).53 (TDO), XC9572XL(RAM).28 (TDI)
TDO: BYPASS.2, JTAG.3, XC9572XL(RAM).53 (TDO)
TMS: JTAG.1, XC9572XL(BUS).29 (TMS), XC9572XL(RAM).29 (TMS)
UDS: XC9572XL(BUS).7 (PB02/17); also elsewhere on the board
VCC: C2.1, IC5.5 (VCC), JP7.2, U1.3 (IN), U$1.11 (VCC), U$1.33 (VCC), U$2.11 (VCC), U$2.33 (VCC), U$3.11 (VCC), U$3.33 (VCC), U$4.11 (VCC), U$4.33 (VCC); also elsewhere on the board
VCC33: C1.1, C7.1, C12.1, JTAG.6, OSC1.4 (VCC), SPIPORT.1, SPIPORT.2, U1.2 (OUT), U1.4 (OUT), XC9572XL(BUS).3 (VCCINT), XC9572XL(BUS).26 (VCCIO), XC9572XL(BUS).37 (VCCINT/VPP), XC9572XL(BUS).55 (VCCIO), XC9572XL(RAM).3 (VCCINT), XC9572XL(RAM).26 (VCCIO), XC9572XL(RAM).37 (VCCINT/VPP), XC9572XL(RAM).55 (VCCIO); also elsewhere on the board
VMA: XC9572XL(BUS).19 (PB01/15); also elsewhere on the board
VPA: XC9572XL(BUS).25 (PB03/8); also elsewhere on the board

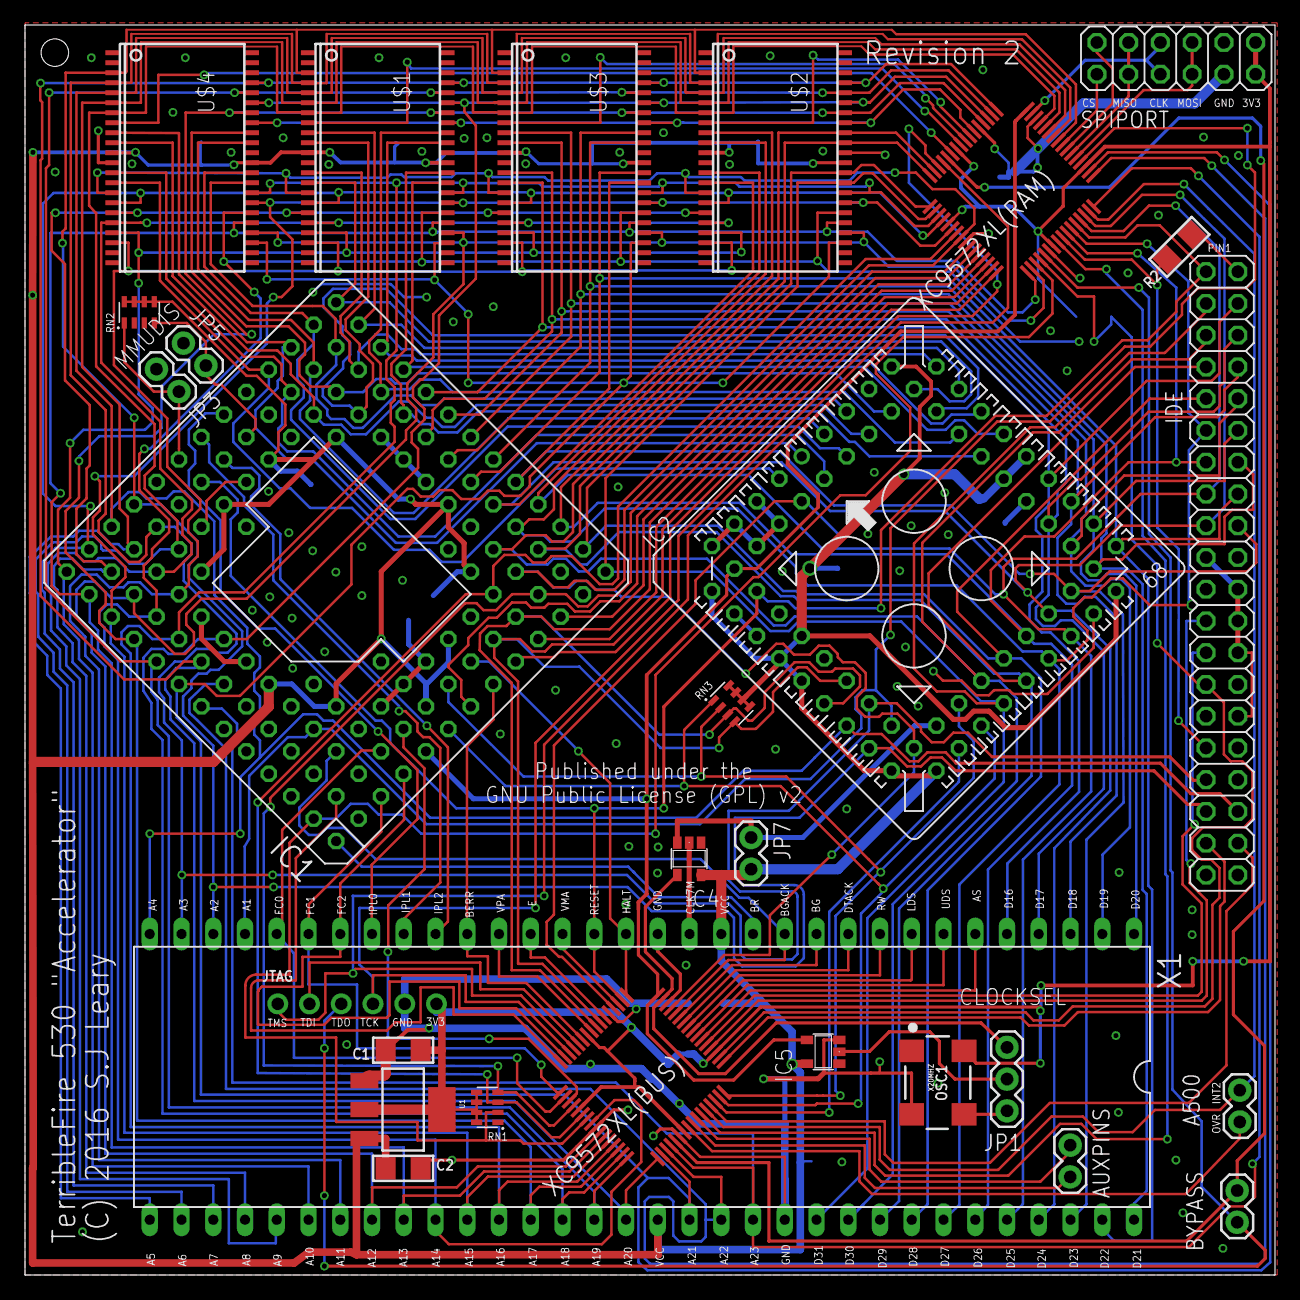
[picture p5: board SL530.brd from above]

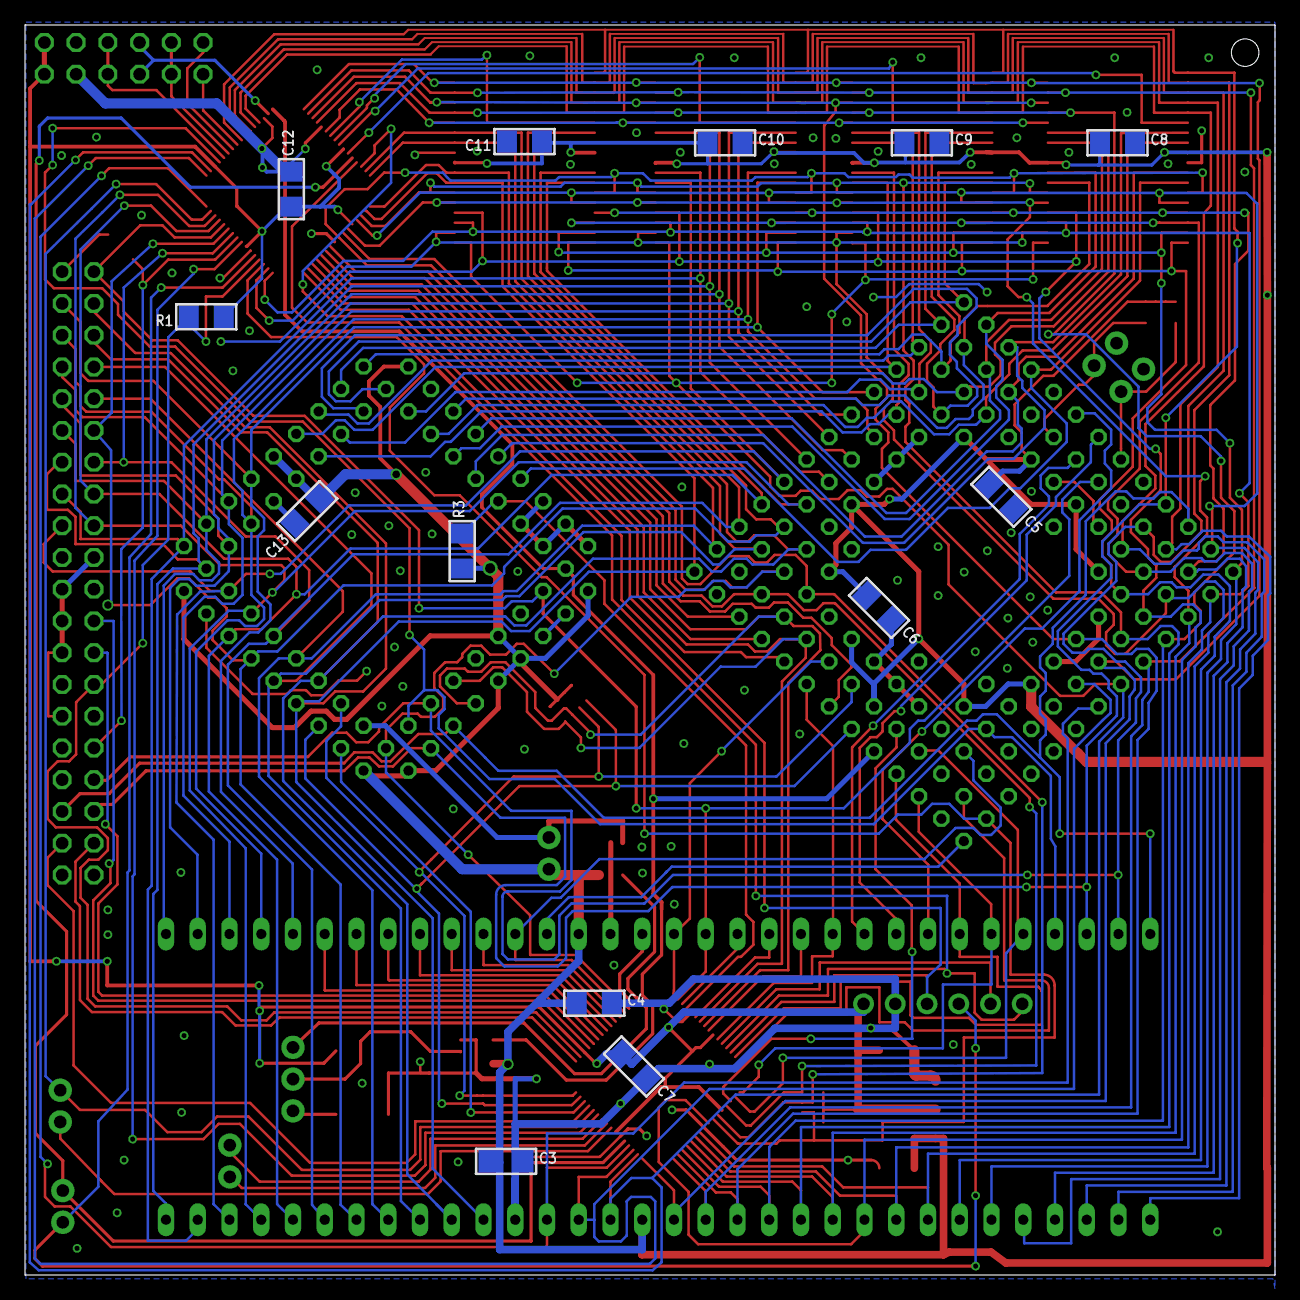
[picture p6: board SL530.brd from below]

Board: 2 copper layers, 100.0 x 100.0 mm, 42 parts (13 on the bottom side), 127 nets.

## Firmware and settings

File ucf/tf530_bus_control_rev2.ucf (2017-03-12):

# Copyright (C) 2016-2017, Stephen J. Leary
# All rights reserved.
#
# This file is part of TF530 (Terrible Fire 030 Accelerator)
#
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
#Clocks
NET "CLKCPU"		LOC="16";
NET "CLKCPU" BUFG=CLK;
NET "CLKCPU" TNM_NET = "CLKCPU"; # gives the net clk a group name as CLKCPU
TIMESPEC "TS_CLKCPU" = PERIOD "CLKCPU" 20 ns ; # add 20 ns PERIOD constraint the
OFFSET = IN 5 ns BEFORE "CLKCPU" ; # add  offset in constraint
OFFSET = OUT 5 ns AFTER "CLKCPU" ; # add  offset out constraint

NET "CLK7M"		LOC="15";
NET "CLK7M" BUFG=CLK;
NET "CLK7M" TNM_NET = "CLK7M"; # gives the net clk a group name as CLK7M
TIMESPEC "TS_CLK7M" = PERIOD "CLK7M" 139 ns ; # add 139 ns PERIOD constraint the
OFFSET = IN 15 ns BEFORE "CLK7M" ; # add  offset in constraint
OFFSET = OUT 15 ns AFTER "CLK7M" ; # add  offset out constraint

NET "A0"      LOC="39";
NET "A<12>"      LOC="42";
NET "A<13>"      LOC="43";
NET "A<14>"      LOC="40";
NET "A<15>"      LOC="44";
NET "A<16>"      LOC="45";
NET "A<17>"      LOC="46";
NET "A<18>"      LOC="47";
NET "A<19>"      LOC="48";
NET "A<20>"      LOC="49";
NET "A<21>"      LOC="50";
NET "A<22>"      LOC="51";
NET "A<23>"      LOC="52";
NET "AS"      LOC="6";
NET "AS20"      LOC="23";
#NET "AUX<0>"      LOC="58";
#NET "AUX<1>"      LOC="57";
NET "AVEC"      LOC="35";
NET "BERR"      LOC="27";
NET "BG"      LOC="11";
NET "BG20"      LOC="32";
NET "BGACK"      LOC="12";
NET "CPCS"      LOC="62";
NET "CPSENSE"      LOC="20";
NET "DS20"      LOC="24";
NET "DSACK<0>"      LOC="63";
NET "DSACK<1>"      LOC="64";
NET "DTACK"      LOC="10";
NET "E"      LOC="22";
NET "FC<0>"      LOC="34";
NET "FC<1>"      LOC="33";
NET "FC<2>"      LOC="31";
#NET "HALT"      LOC="17";
NET "IDECS<0>"      LOC="1";
NET "IDECS<1>"      LOC="61";
NET "IDEWAIT"      LOC="2";
#NET "INT2"      LOC="60";
NET "INTSIG"      LOC="59";
NET "IOR"      LOC="5";
NET "IOW"      LOC="4";
NET "LDS"      LOC="8";
NET "OVR"      LOC="56";
NET "RW00"      LOC="9";
NET "RW20"      LOC="13";
#NET "RESET"      LOC="18";
NET "SIZ<0>"      LOC="36";
NET "SIZ<1>"      LOC="38";
NET "UDS"      LOC="7";
NET "VMA"      LOC="19";
NET "VPA"      LOC="25";

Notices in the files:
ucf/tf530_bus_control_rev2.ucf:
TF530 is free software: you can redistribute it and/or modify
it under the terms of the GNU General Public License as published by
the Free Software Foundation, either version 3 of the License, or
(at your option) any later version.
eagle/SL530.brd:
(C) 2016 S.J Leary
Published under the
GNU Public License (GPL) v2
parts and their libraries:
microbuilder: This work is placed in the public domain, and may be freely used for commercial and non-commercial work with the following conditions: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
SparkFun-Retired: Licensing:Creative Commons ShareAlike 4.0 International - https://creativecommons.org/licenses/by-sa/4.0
